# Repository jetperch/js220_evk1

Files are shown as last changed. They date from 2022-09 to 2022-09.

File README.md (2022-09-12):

# JS220 Evaluation Kit 1

Welcome to the Joulescope JS220 Evaluation Kit 1 (EVK) project.  This EVK
provides a quick and easy way to get started measuring real waveforms with
your Joulescope.  The goal of the EVK is to toggle signals to vary the load.  
Your JS220 will measure this change and display the current waveform in the 
Joulescope UI. 

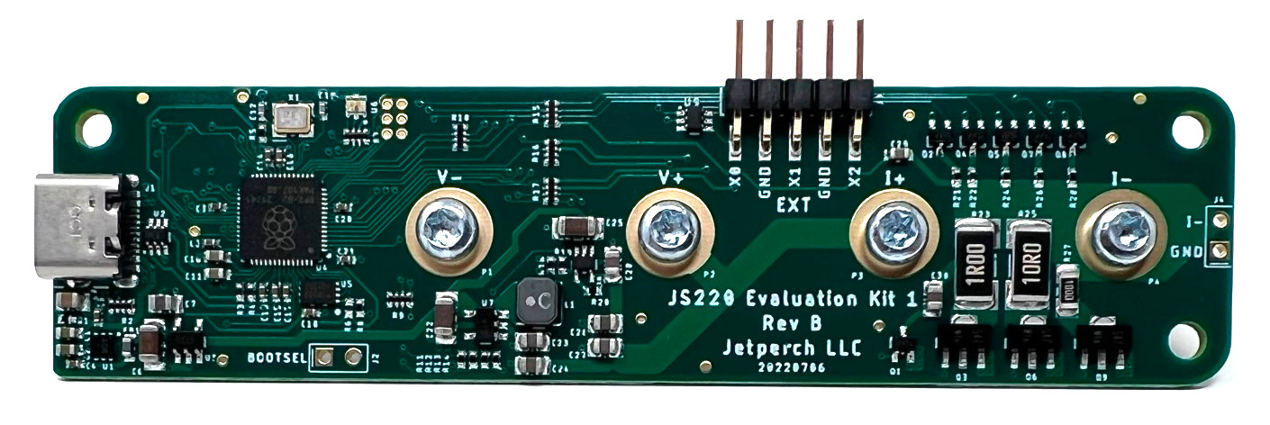
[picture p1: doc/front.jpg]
EVK1 board


To get started, connect your JS220 to your host computer.  Install and
start the Joulescope UI.  Select View → Oscilloscope.  

Now plug the EVK into your JS220, like this:

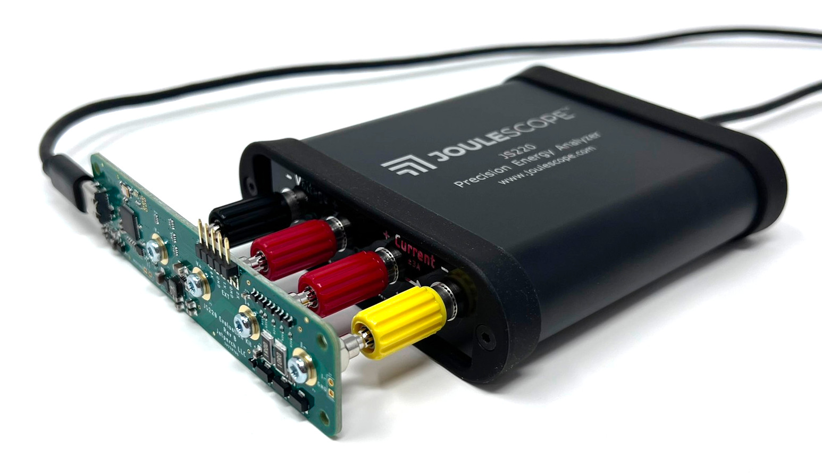
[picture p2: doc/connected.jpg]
EVK1 config


Use the provided USB-C to USB-A cable to connect the EVK to your
host computer.  The Joulescope UI should display an interesting waveform,
like this:

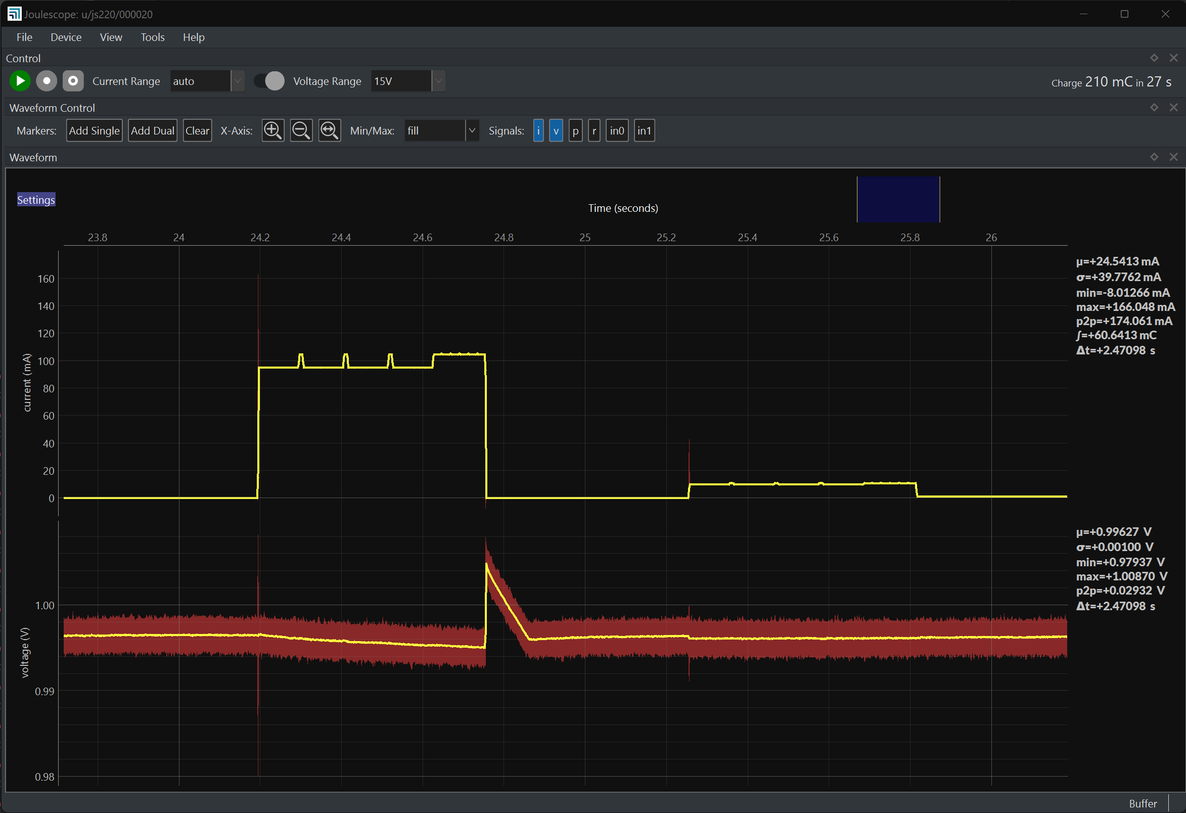
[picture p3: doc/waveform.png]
EVK1 waveform


The EVK hardware and firmware are open source and available on 
[GitHub](https://github.com/jetperch/js220_evk1).  View the 
[schematic](https://github.com/jetperch/js220_evk1/blob/main/hardware/js220_evk1.pdf).

The EVK produces this waveform by default.  The EVK is also very flexible.
The EVK runs MicroPython for easy configuration and programming over a
USB-CDC serial port interface.

To get started with MicroPython on your EVK:

1. Connect the EVK to your host computer using the provided USB cable.
2. Install [Thonny](https://thonny.org/)
3. Launch Thonny
4. Select Run → Select interpretter...
   a. Select MicroPython (Raspberry Pi Pico)
   b. Leave port set to <Try to detect port automatically>
   c. OK
5. The "Shell" area at the bottom should display the MicroPython banner ">>>"

You can then run some other tests or create your own.

To stop any load sequence and return to a high impedance load:

    evk.stop()

To power off the supply:

    evk.power_off()

To disable both power and load:

    evk.off()

To run the demo again:

    evk.demo()

To run a simple descending pattern with the buck converter:

    evk.current_range_tester(use_buck=True)

To run a more complicated descending patterh with the buck converter:

    evk.off()
    evk.power_buck(0.6)
    evk.pio_start_sequence(frequency=10_000, sequence='descend')

To provide 1 V from the LDO into a 1 kΩ load:

    evk.off()
    evk.power_ldo(1.0)
    evk.resistance = 1000

To provide 3.3V from the buck converter into a load 1 kΩ || 10 µF:

    evk.off()
    evk.power_ldo(1.0)
    evk.resistance = 1000
    evk.c_10U.on()

To enable both the 1 kΩ and 100 Ω resistors with the 10 µF capacitor:

    evk.stop()
    evk.resistance_on(1000)
    evk.resistance_on(100)
    evk.c_10U.on()

Alternatively:

    evk.stop()
    evk.resistance_mask_on(0x0C)
    evk.c_10U.on()

To disconnect the 10 µF capacitor:
    
    evk.c_10U.off()

To use the PWM capacitor to drive a bipolar current:

    evk.off()
    evk.power_ldo(3.3)
    evk.c_pwm_start(10_000, 0x8000)

To change the LED color to blue:
    
    led.u8(red=0, green=0, blue=255)

You can also animate the LED:

    led.animate_fade([0x00ff00, 0, 0])
    led.animate_rainbow()
    led.stop()

## References:

* [MicroPython](https://micropython.org/)
  * [GitHub](https://github.com/micropython/micropython)
* [Thonny](https://thonny.org/)
* [MicroPython on Raspberry Pi](https://www.raspberrypi.com/documentation/microcontrollers/micropython.html)
  * [Raspberry Pi Pico Python SDK](https://datasheets.raspberrypi.com/pico/raspberry-pi-pico-python-sdk.pdf)
  * [API documentation](https://docs.micropython.org/en/latest/library/rp2.html)
  * [Pico Micropython Examples](https://github.com/raspberrypi/pico-micropython-examples/)
* [Raspberry Pi RP2040 Documentation](https://www.raspberrypi.com/documentation/microcontrollers/rp2040.html)
  * [Pico PIO Examples](https://github.com/raspberrypi/pico-examples/tree/master/pio)
  * [Pico Examples](https://github.com/raspberrypi/pico-examples) for C SDK
    * [Logic Analyzer](https://github.com/raspberrypi/pico-examples/blob/master/pio/logic_analyser/logic_analyser.c) PIO + DMA
    * [PIO](https://github.com/raspberrypi/pico-examples/tree/master/pio)
    * [DMA](https://github.com/raspberrypi/pico-examples/tree/master/dma)
* Controlling the EVK from your host computer
  * [pyboard.py](https://github.com/micropython/micropython/blob/master/tools/pyboard.py)
  * [rshell](https://github.com/dhylands/rshell)
  * [ampy](https://github.com/scientifichackers/ampy)

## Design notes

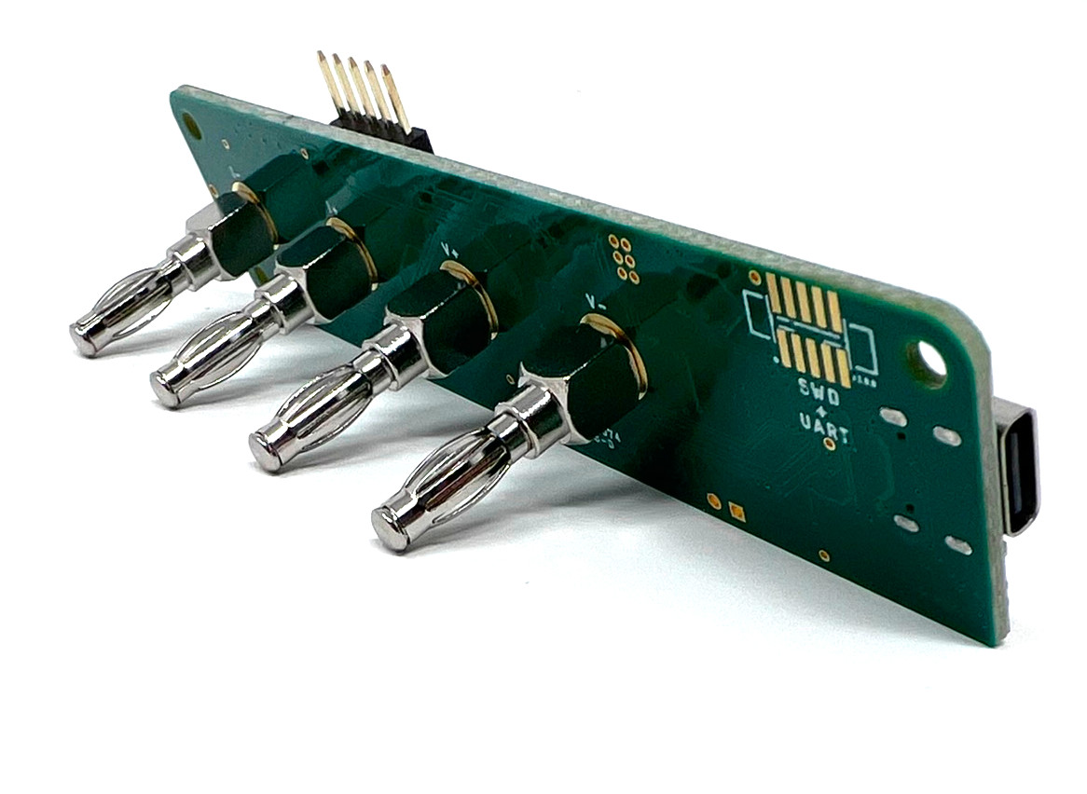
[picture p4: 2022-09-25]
doc/back.jpg

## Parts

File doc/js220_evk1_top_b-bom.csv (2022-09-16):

BOM Qty | Part/BOM Name | Description | Designators | Comments
1 | 6 x 5 x 2" White Box | 6 x 5 x 2" White Indestructo Mailers 100/bundle
1 | Anti-Static Self-Seal Bubble Bags 6 x 8 1/2" | Anti-Static Bubble Bags - Self-Seal, 6 x 8 1/2" 250/carton
1 | ESD warning label 2x2" | Static Warning Labels - "Attention…Electrostatic Sensitive Devices", 2 x 2" 500/roll
1 | USB_AM_CM_150_A | USB 2.0 high-speed 1.5 meter, black color, A male to C male, rev A
1 | js220_evk1_label | JS220 EVK1 UPC barcode label
1 | js220_evk1_pcba_b | JS220 Evaluation Kit 1, Printed Circuit Board Assembly, rev B
1 | js220_evk1_qs_a | JS220 Evaluation Kit 1 quick start guide, rev A

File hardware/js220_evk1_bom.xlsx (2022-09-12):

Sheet: All
BOM - All
2022 July 06
# | Qty | Ref Des | Name
1 | 2 | R3, R4 | R0402-27-1%
2 | 3 | R5, R8, R28 | R0402-1k-0.1%
3 | 1 | R13 | R0402-2.21k-0.1%
4 | 1 | R12 | R0402-2.8k-0.1%
5 | 1 | R19 | R0402-4.32k-1%
6 | 1 | R18 | R0402-8.45k-1%
7 | 4 | R11, R14, R20, R26 | R0402-10k-0.1%
8 | 1 | R24 | R0402-100k-0.1%
9 | 1 | R1 | R0402-267k-1%
10 | 1 | R22 | R0402-1M-1%
11 | 1 | R21 | R0402-10M-1%
12 | 1 | R27 | R1206-100-1%
13 | 1 | R23 | R2512-1-1%
14 | 1 | R25 | R2512-10-1%
15 | 3 | R7, R10, R16 | R4_0804-270-5%
16 | 2 | R15, R17 | R4_0804-1k-5%
17 | 2 | R2, R9 | R4_0804-4.7k-5%
18 | 2 | C12, C19 | C0402-30p-C0G-50V-5%
19 | 2 | C4, C5 | C0402-10n-X7R-50V-10%
20 | 10 | C8, C9, C13, C14, C15, C16, C17, C18, C20, C21 | C0402-100n-X7R-50V-10%
21 | 5 | C1, C2, C10, C11, C29 | C0603-1u-X5R-50V-20%
22 | 1 | C3 | C0805-1n-X5R-1000V-20%
23 | 7 | C7, C23, C24, C26, C27, C28, C30 | C0805-10u-X5R-6.3V-20%
24 | 3 | C6, C22, C25 | C1206-10u-X5R-10V-20%
25 | 1 | FB1 | FB0603_470
26 | 1 | L1 | NRS4018T2R2MDGJ
27 | 1 | X1 | ABM8-12.000MHZ-20-B1U-T
28 | 5 | Q2, Q4, Q5, Q7, Q8 | BC848W
29 | 1 | Q1 | BSS214NWH6327XTSA1
30 | 3 | Q3, Q6, Q9 | PBSS4240X
31 | 1 | U6 | 19-337C/RSBHGHC-A88/4T
32 | 1 | U3 | MIC5225-3.3YM5-TR
33 | 1 | U8 | MIC5377YC5-TR
34 | 1 | U1 | NCP361MUTBG
35 | 1 | U4 | RP2040
36 | 1 | U7 | TLV62565DBV
37 | 2 | U2, U9 | TPD4E1U06DCK
38 | 1 | U5 | W25Q16JVUXIQ TR
39 | 1 | J3 | M20-8890545R
40 | 1 | J1 | USB4105-GF-A
41 | 4 | P1, P2, P3, P4 | P55-271F40N
42 | 1 | PCB1 | JS220_evk1_pcb_revB
43 | 4 | U$1, U$2, U$3, U$4 | screw_0002
 | 89

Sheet: Top
BOM - Top
2022 July 06
# | Qty | Ref Des | Name
1 | 2 | R3, R4 | R0402-27-1%
2 | 3 | R5, R8, R28 | R0402-1k-0.1%
3 | 1 | R13 | R0402-2.21k-0.1%
4 | 1 | R12 | R0402-2.8k-0.1%
5 | 1 | R19 | R0402-4.32k-1%
6 | 1 | R18 | R0402-8.45k-1%
7 | 4 | R11, R14, R20, R26 | R0402-10k-0.1%
8 | 1 | R24 | R0402-100k-0.1%
9 | 1 | R1 | R0402-267k-1%
10 | 1 | R22 | R0402-1M-1%
11 | 1 | R21 | R0402-10M-1%
12 | 1 | R27 | R1206-100-1%
13 | 1 | R23 | R2512-1-1%
14 | 1 | R25 | R2512-10-1%
15 | 3 | R7, R10, R16 | R4_0804-270-5%
16 | 2 | R15, R17 | R4_0804-1k-5%
17 | 2 | R2, R9 | R4_0804-4.7k-5%
18 | 2 | C12, C19 | C0402-30p-C0G-50V-5%
19 | 2 | C4, C5 | C0402-10n-X7R-50V-10%
20 | 10 | C8, C9, C13, C14, C15, C16, C17, C18, C20, C21 | C0402-100n-X7R-50V-10%
21 | 5 | C1, C2, C10, C11, C29 | C0603-1u-X5R-50V-20%
22 | 1 | C3 | C0805-1n-X5R-1000V-20%
23 | 7 | C7, C23, C24, C26, C27, C28, C30 | C0805-10u-X5R-6.3V-20%
24 | 3 | C6, C22, C25 | C1206-10u-X5R-10V-20%
25 | 1 | FB1 | FB0603_470
26 | 1 | L1 | NRS4018T2R2MDGJ
27 | 1 | X1 | ABM8-12.000MHZ-20-B1U-T
28 | 5 | Q2, Q4, Q5, Q7, Q8 | BC848W
29 | 1 | Q1 | BSS214NWH6327XTSA1
30 | 3 | Q3, Q6, Q9 | PBSS4240X
31 | 1 | U6 | 19-337C/RSBHGHC-A88/4T
32 | 1 | U3 | MIC5225-3.3YM5-TR
33 | 1 | U8 | MIC5377YC5-TR
34 | 1 | U1 | NCP361MUTBG
35 | 1 | U4 | RP2040
36 | 1 | U7 | TLV62565DBV
37 | 2 | U2, U9 | TPD4E1U06DCK
38 | 1 | U5 | W25Q16JVUXIQ TR
39 | 1 | J3 | M20-8890545R
40 | 1 | J1 | USB4105-GF-A
41 | 4 | P1, P2, P3, P4 | P55-271F40N
42 | 1 | PCB1 | JS220_evk1_pcb_revB
43 | 4 | U$1, U$2, U$3, U$4 | screw_0002
 | 89

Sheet: Bottom
BOM - Bottom
2022 July 06
# | Qty | Ref Des | Name
 | 0

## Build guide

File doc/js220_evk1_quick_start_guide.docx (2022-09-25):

Joulescope JS220 Evaluation Kit 1

Quick Start Guide

This Joulescope™ JS220 Evaluation Kit 1 (EVK) provides a quick and easy way to measure real waveforms with a Joulescope JS220. Power the EVK with the provided USB C to A cable. The EVK plugs directly into the sensor-side of the JS220, and it generates high-dynamic current waveforms for analysis by the JS220.

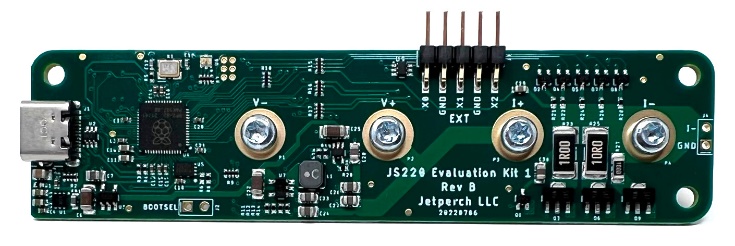
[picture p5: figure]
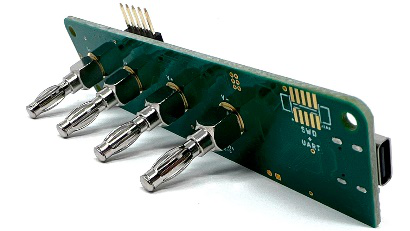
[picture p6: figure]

Kit Contents:

- JS220 EVK1 board
- USB A to C cable
- Joulescope sticker

You will need to provide a Joulescope JS220 and a host computer. The host computer must have two available USB A ports, one for the JS220 and one for the EVK.

1. Connect the EVK to the JS220 sensor-side binding posts. Use both hands and avoid the protruding expansion connector header.
2. Use the provided USB cable to connect the EVK to the host computer.
3. Use the JS220’s USB cable to connect the JS220 to the host computer.
4. Launch the Joulescope software to capture and explore!

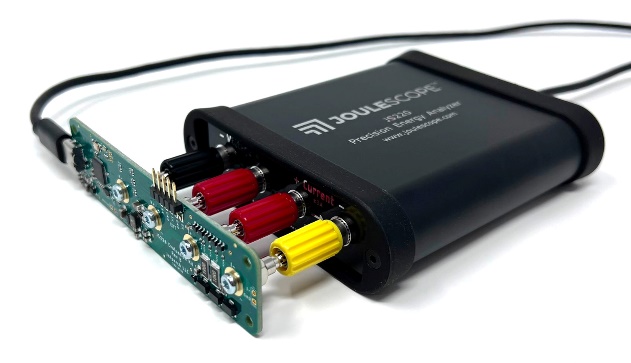
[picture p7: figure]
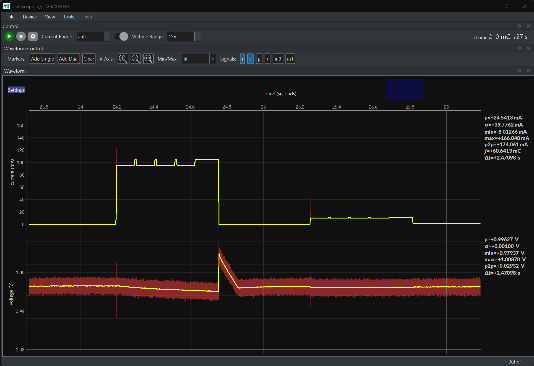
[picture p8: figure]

You can easily control the EVK to generate other waveforms and interact with GPIO. The entire hardware and software design is open source using Micropython. For more detailed instructions and information, visit joulescope.com/js220_evk1

⚠️ | The EVK is provided for evaluation only and does not have FCC, CE, or USB certifications. You are responsible for operating the EVK in compliance with any local regulations.

If you have any questions, please contact support@joulescope.com!

© 2022 Jetperch LLC Rev 2

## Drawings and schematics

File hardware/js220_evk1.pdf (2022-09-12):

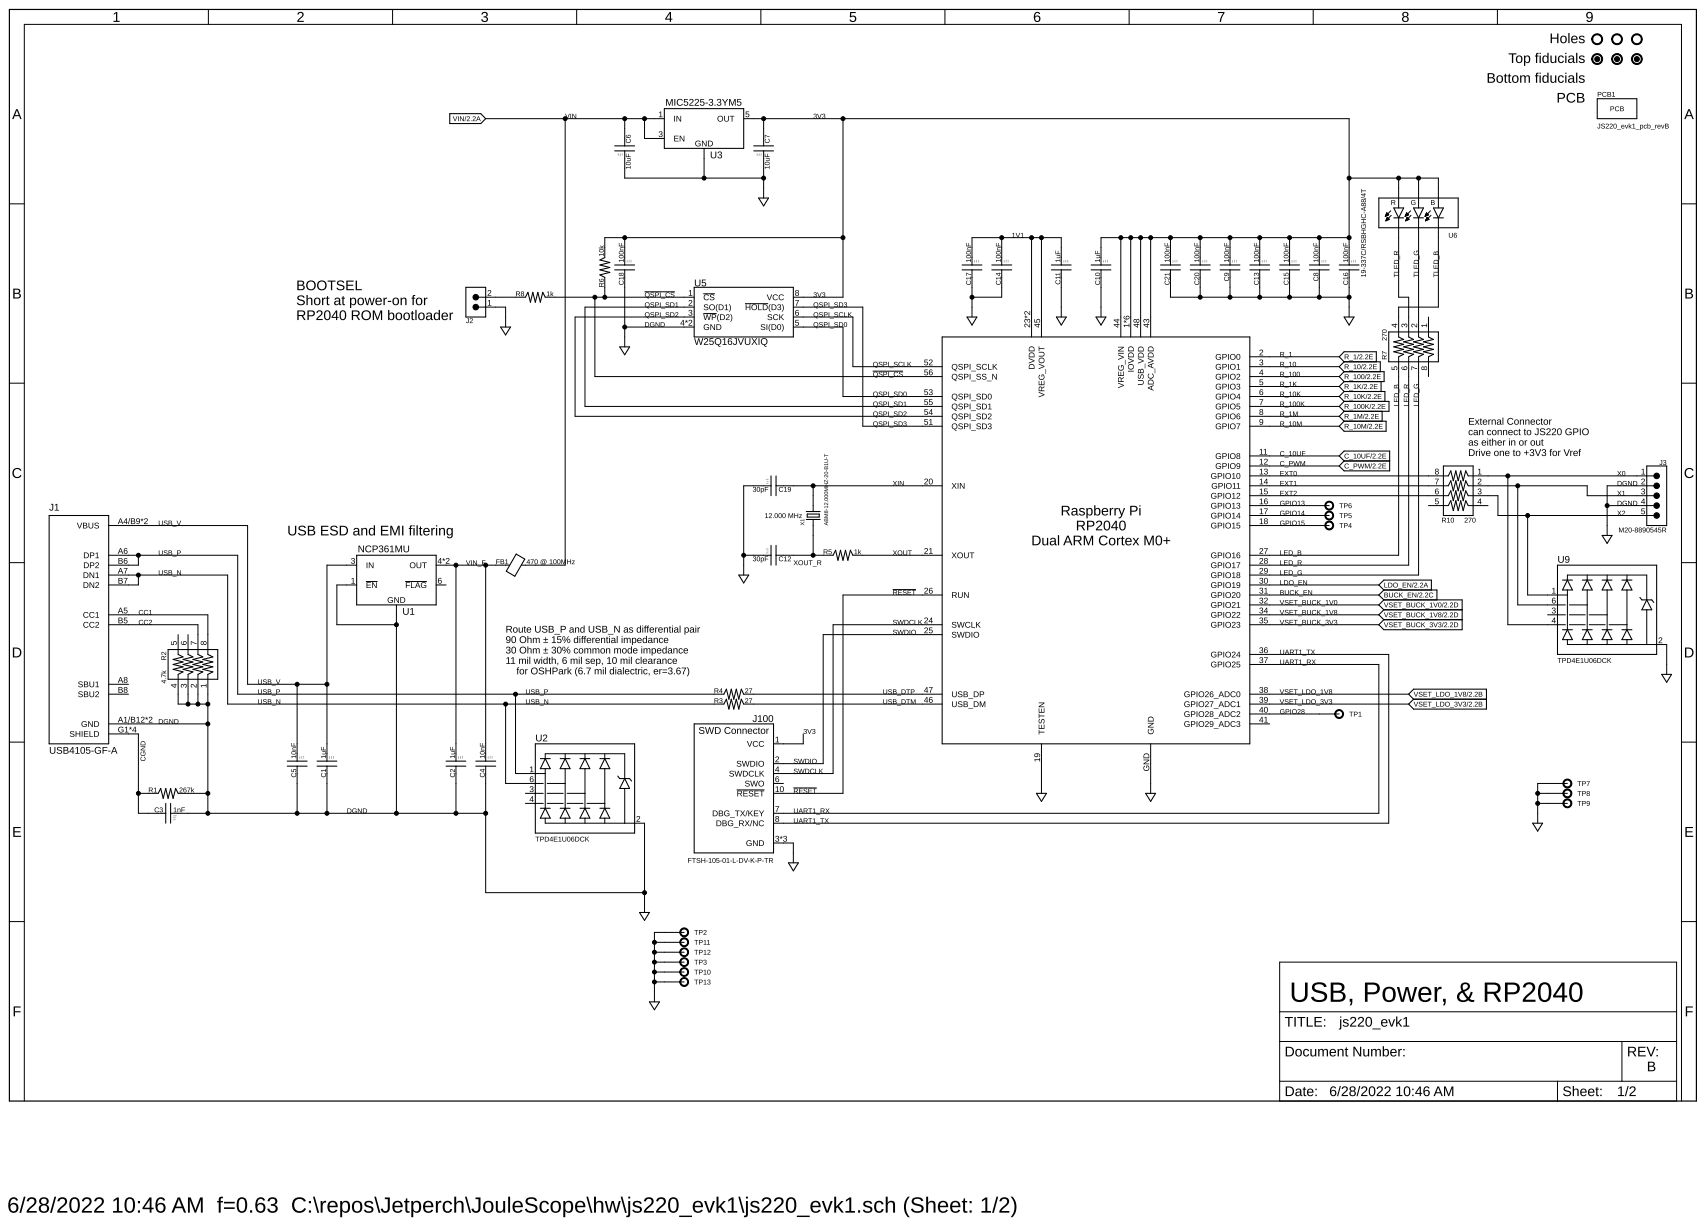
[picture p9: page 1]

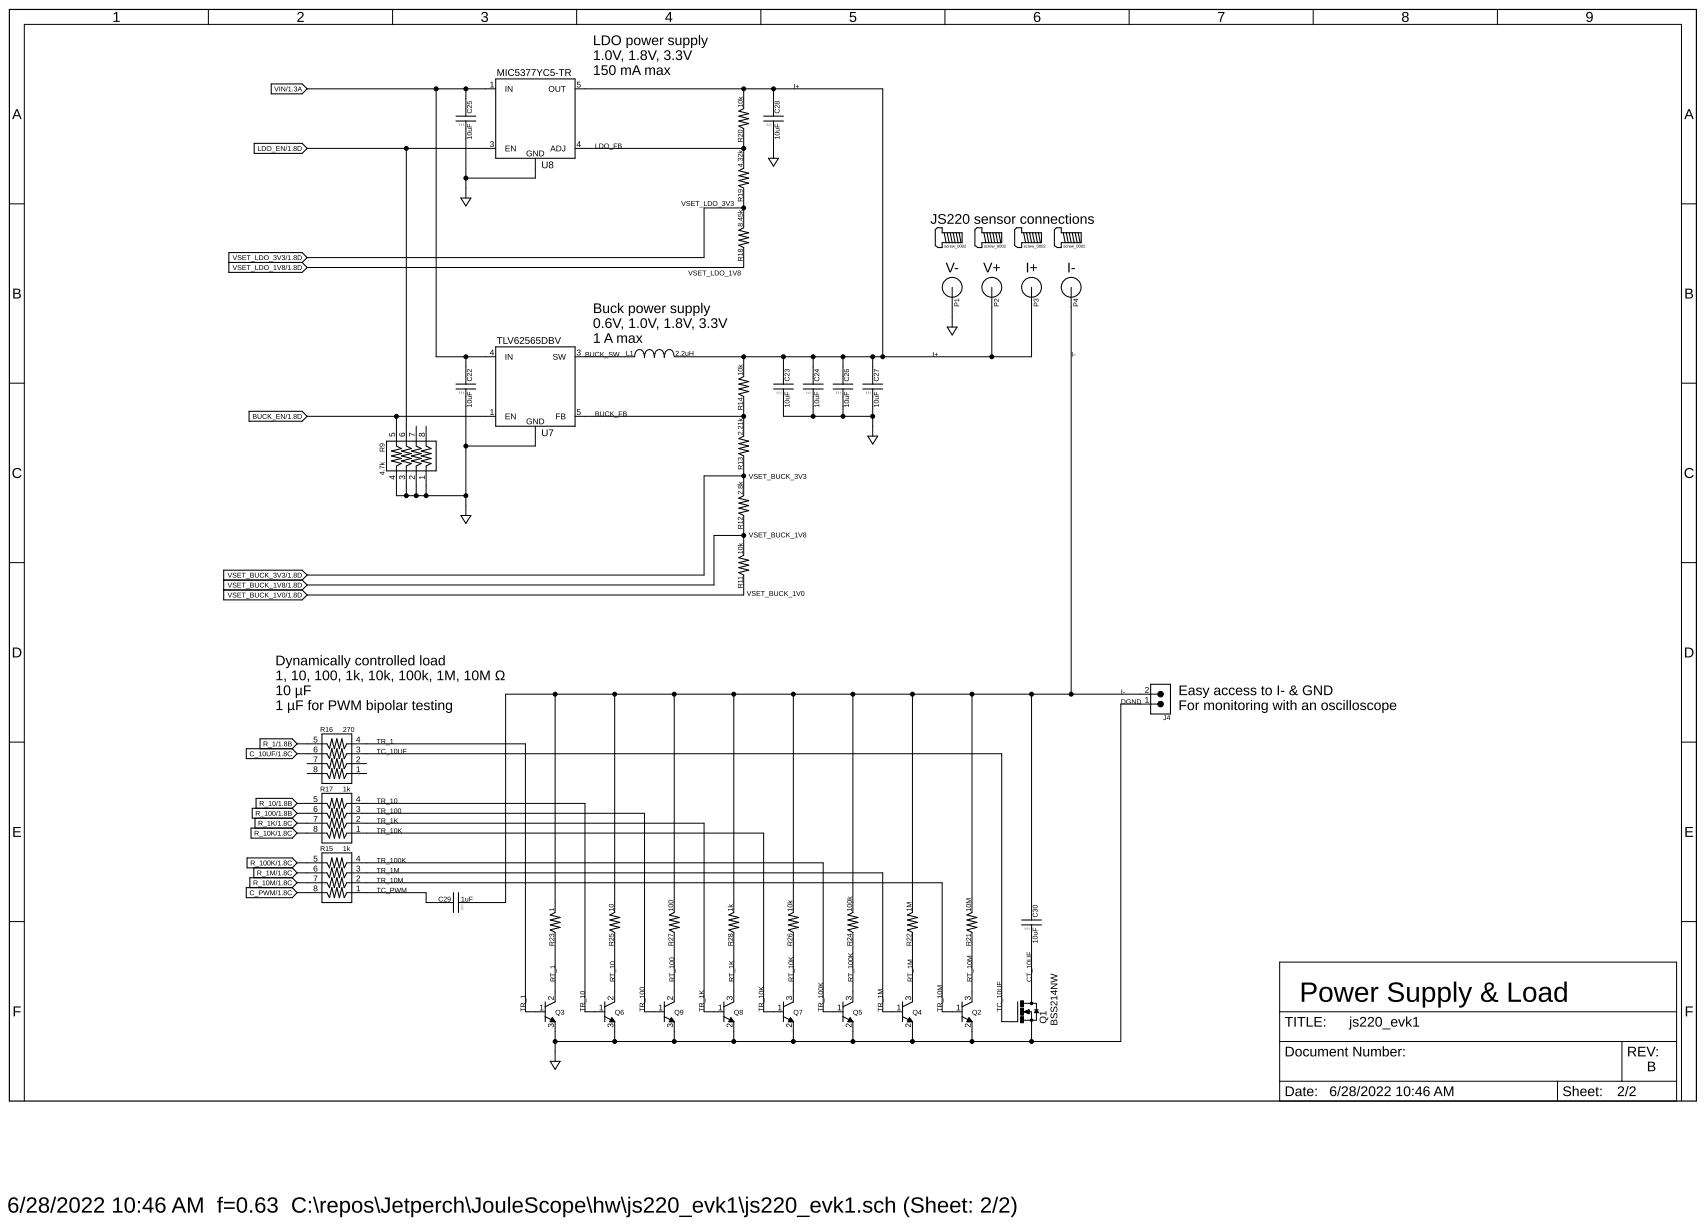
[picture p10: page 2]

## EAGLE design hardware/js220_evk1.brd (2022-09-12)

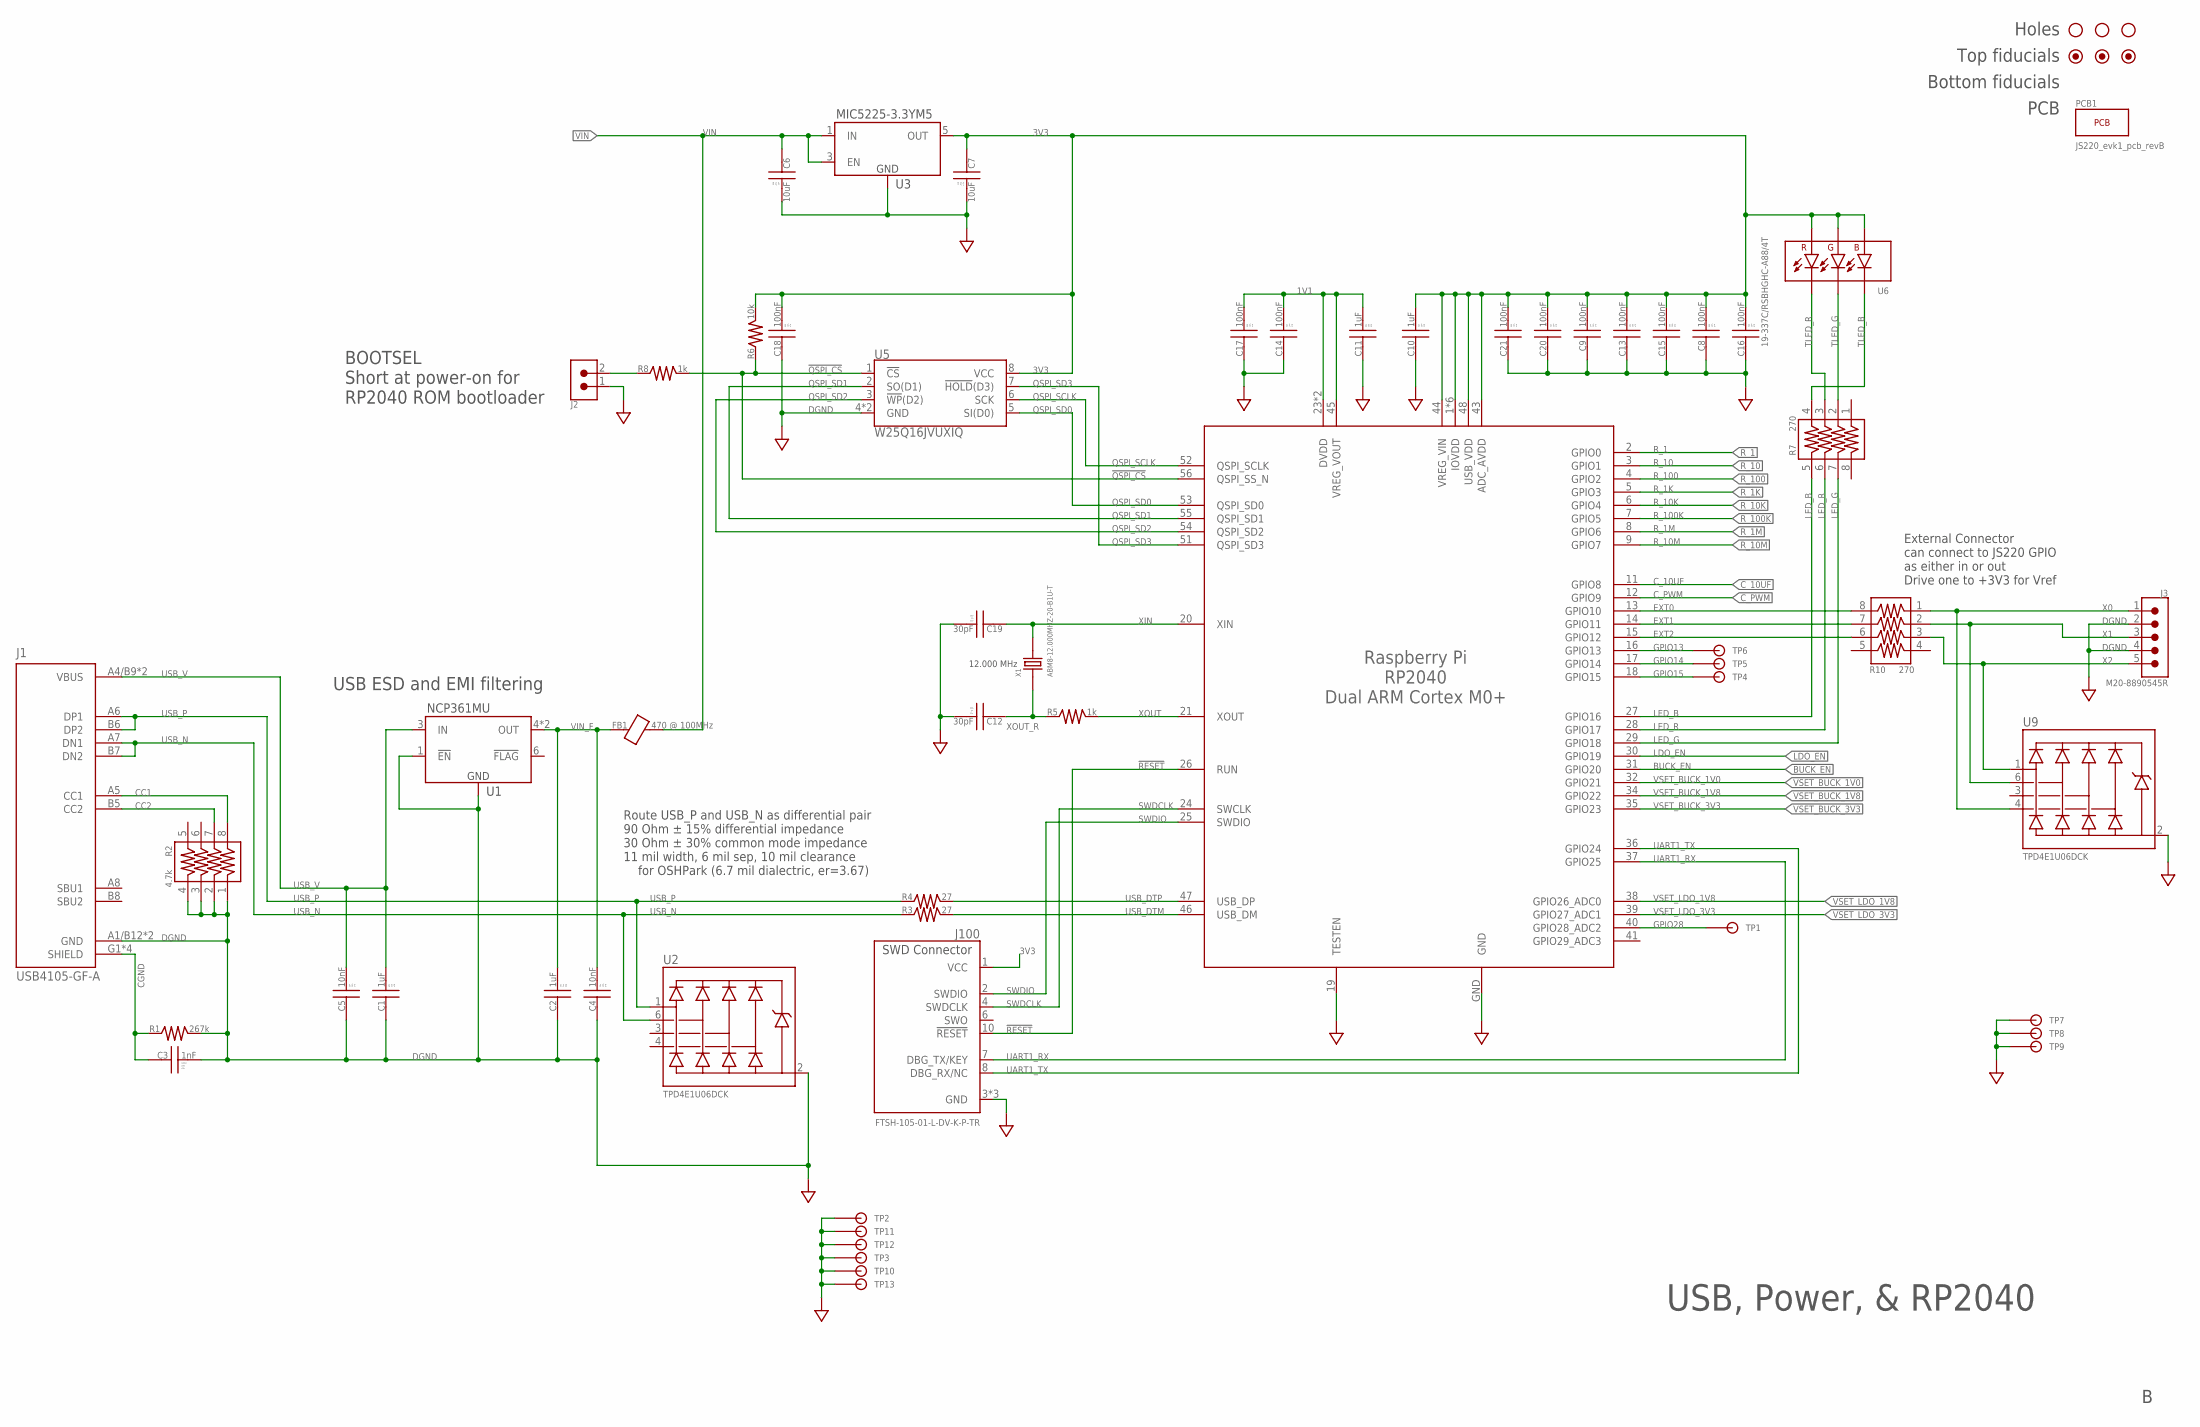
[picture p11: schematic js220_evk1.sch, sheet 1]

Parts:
C1, C2, C10, C11: 1uF; 0603; TOLERANCE 20%; VOLTAGE 50V
C3: 1nF; 0805; TOLERANCE 20%; VOLTAGE 1000V
C4, C5: 10nF; 0402; TOLERANCE 10%; VOLTAGE 50V
C6: 10uF; 1206; TOLERANCE 20%; VOLTAGE 10V
C7: 10uF; 0805; TOLERANCE 20%; VOLTAGE 6.3V
C8, C9, C13, C14, C15, C16, C17, C18, C20, C21: 100nF; 0402; TOLERANCE 10%; VOLTAGE 50V
C12, C19: 30pF; 0402; TOLERANCE 5%; VOLTAGE 50V
FB1: 470 @ 100MHz; 0603
FD1, FD2, FD3: DNI; FIDUCIAL_1MM_2MM
H1, H2, H3: STAND-OFFTIGHT; STAND-OFF-TIGHT
J1: USB4105-GF-A; GCT_USB4105_REVA; MPN USB4105-GF-A
J2: CONN_0.1_2X1; CONN_0.1_2X1_M
J3: M20-8890545R; CONN_0.1_5X1_MSR; MPN M20-8890545R
J100: FTSH-105-01-L-DV-K-P-TR; CONN_0.050_5X2_M_SM; MPN FTSH-105-01-L-DV-K-P-TR
R1: 267k; 0402; TOLERANCE 1%
R2: 4.7k; 0402X4; TOLERANCE 5%
R3, R4: 27; 0402; TOLERANCE 1%
R5, R8: 1k; 0402; TOLERANCE 0.1%
R6: 10k; 0402; TOLERANCE 0.1%
R7, R10: 270; 0402X4; TOLERANCE 5%
TP1, TP2, TP3, TP4, TP5, TP6, TP7, TP8, TP9, TP10, TP11, TP12, TP13: TPTP-PTH0.02; TP-PTH0.02
U1: NCP361MU; UDFN-6; MPN NCP361MUTBG
U2, U9: TPD4E1U06DCK; SC-70-6
U3: MIC5225-3.3YM5; SOT23-5; MPN MIC5225-3.3YM5-TR
U4: RP2040; QFN-56G; MPN RP2040
U5: W25Q16JVUXIQ; USON-8_2X3; MPN W25Q16JVUXIQ TR
U6: 19-337C/RSBHGHC-A88/4T; LED_RGB6_1.6X1.6; MPN 19-337C/RSBHGHC-A88/4T
X1: ABM8-12.000MHZ-20-B1U-T; XTAL4_3.2X2.5; MPN ABM8-12.000MHZ-20-B1U-T

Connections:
1V1: C11.2, C14.2, C17.2, U4.23 (DVDD), U4.45 (VREG_VOUT), U4.50 (DVDD)
3V3: C7.1, C8.2, C9.2, C10.2, C13.2, C15.2, C16.2, C18.2, C20.2, C21.2, J100.1 (VCC), R6.2, U3.5 (OUT), U4.1 (IOVDD), U4.10 (IOVDD), U4.22 (IOVDD), U4.33 (IOVDD), U4.42 (IOVDD), U4.43 (ADC_AVDD), U4.44 (VREG_VIN), U4.48 (USB_VDD), U4.49 (IOVDD), U5.8 (VCC), U6.2 (GREEN_ANODE+), U6.4 (RED_ANODE+), U6.6 (BLUE_ANODE+)
!QSPI_CS: R6.1, R8.2, U4.56 (QSPI_SS_N), U5.1 (!CS!)
!RESET: J100.10 (!RESET), U4.26 (RUN)
BUCK_EN: U4.31 (GPIO20); also elsewhere on the board
CC1: J1.A5 (CC1), R2.8 (1B)
CC2: J1.B5 (CC2), R2.7 (2B)
CGND: C3.1, J1.G1 (SHIELD), J1.G2 (SHIELD), J1.G3 (SHIELD), J1.G4 (SHIELD), R1.1
C_10UF: U4.11 (GPIO8); also elsewhere on the board
C_PWM: U4.12 (GPIO9); also elsewhere on the board
DGND: C1.1, C2.1, C3.2, C4.1, C5.1, C6.2, C7.2, C8.1, C9.1, C10.1, C11.1, C12.2, C13.1, C14.1, C15.1, C16.1, C17.1, C18.1, C19.2, C20.1, C21.1, J1.A1/B12 (GND), J1.B1/A12 (GND), J2.1, J3.2, J3.4, J100.3 (GND), J100.5 (GND), J100.9 (GND), R1.2, R2.1 (1A), R2.2 (2A), R2.3 (3A), R2.4 (4A), TP2.1, TP3.1, TP7.1, TP8.1, TP9.1, TP10.1, TP11.1, TP12.1, TP13.1, U1.1 (!EN), U1.2 (GND), U1.GND@PAD (GND), U2.2 (GND), U3.2 (GND), U4.19 (TESTEN), U4.GND, U5.4 (GND), U5.9 (GND), U9.2 (GND); also elsewhere on the board
EXT0: R10.8 (1B), U4.13 (GPIO10)
EXT1: R10.7 (2B), U4.14 (GPIO11)
EXT2: R10.6 (3B), U4.15 (GPIO12)
GPIO13: TP6.1, U4.16 (GPIO13)
GPIO14: TP5.1, U4.17 (GPIO14)
GPIO15: TP4.1, U4.18 (GPIO15)
GPIO28: TP1.1, U4.40 (GPIO28_ADC2)
LDO_EN: U4.30 (GPIO19); also elsewhere on the board
LED_B: R7.5 (4B), U4.27 (GPIO16)
LED_G: R7.7 (2B), U4.29 (GPIO18)
LED_R: R7.6 (3B), U4.28 (GPIO17)
unnamed: J2.2, R8.1
QSPI_SCLK: U4.52 (QSPI_SCLK), U5.6 (SCK)
QSPI_SD0: U4.53 (QSPI_SD0), U5.5 (SI(D0))
QSPI_SD1: U4.55 (QSPI_SD1), U5.2 (SO(D1))
QSPI_SD2: U4.54 (QSPI_SD2), U5.3 (!WP!(D2))
QSPI_SD3: U4.51 (QSPI_SD3), U5.7 (!HOLD!(D3))
R_1: U4.2 (GPIO0); also elsewhere on the board
R_1K: U4.5 (GPIO3); also elsewhere on the board
R_1M: U4.8 (GPIO6); also elsewhere on the board
R_10: U4.3 (GPIO1); also elsewhere on the board
R_10K: U4.6 (GPIO4); also elsewhere on the board
R_10M: U4.9 (GPIO7); also elsewhere on the board
R_100: U4.4 (GPIO2); also elsewhere on the board
R_100K: U4.7 (GPIO5); also elsewhere on the board
SWDCLK: J100.4 (SWDCLK), U4.24 (SWCLK)
SWDIO: J100.2 (SWDIO), U4.25 (SWDIO)
TLED_B: R7.4 (4A), U6.5 (BLUE_CATHODE-)
TLED_G: R7.2 (2A), U6.1 (GREEN_CATHODE-)
TLED_R: R7.3 (3A), U6.3 (RED_CATHODE-)
UART1_RX: J100.7 (DBG_TX/KEY), U4.37 (GPIO25)
UART1_TX: J100.8 (DBG_RX/NC), U4.36 (GPIO24)
USB_DTM: R3.2, U4.46 (USB_DM)
USB_DTP: R4.2, U4.47 (USB_DP)
USB_N: J1.A7 (DN1), J1.B7 (DN2), R3.1, U2.6 (D1-)
USB_P: J1.A6 (DP1), J1.B6 (DP2), R4.1, U2.1 (D1+)
USB_V: C1.2, C5.2, J1.A4/B9 (VBUS), J1.B4/A9 (VBUS), U1.3 (IN)
VIN: C6.1, FB1.2, U3.1 (IN), U3.3 (EN); also elsewhere on the board
VIN_F: C2.2, C4.2, FB1.1, U1.4 (OUT), U1.5 (OUT)
VSET_BUCK_1V0: U4.32 (GPIO21); also elsewhere on the board
VSET_BUCK_1V8: U4.34 (GPIO22); also elsewhere on the board
VSET_BUCK_3V3: U4.35 (GPIO23); also elsewhere on the board
VSET_LDO_1V8: U4.38 (GPIO26_ADC0); also elsewhere on the board
VSET_LDO_3V3: U4.39 (GPIO27_ADC1); also elsewhere on the board
X0: J3.1, R10.1 (1A), U9.4 (D2-)
X1: J3.3, R10.2 (2A), U9.6 (D1-)
X2: J3.5, R10.3 (3A), U9.1 (D1+)
XIN: C19.1, U4.20 (XIN), X1.3 (2)
XOUT: R5.2, U4.21 (XOUT)
XOUT_R: C12.1, R5.1, X1.1

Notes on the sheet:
USB, Power, & RP2040
USB ESD and EMI filtering
Route USB_P and USB_N as differential pair 90 Ohm ± 15% differential impedance 30 Ohm ± 30% common mode impedance 11 mil width, 6 mil sep, 10 mil clearance for OSHPark (6.7 mil dialectric, er=3.67)
12.000 MHz
Holes Top fiducials Bottom fiducials PCB
External Connector can connect to JS220 GPIO as either in or out Drive one to +3V3 for Vref
BOOTSEL Short at power-on for RP2040 ROM bootloader

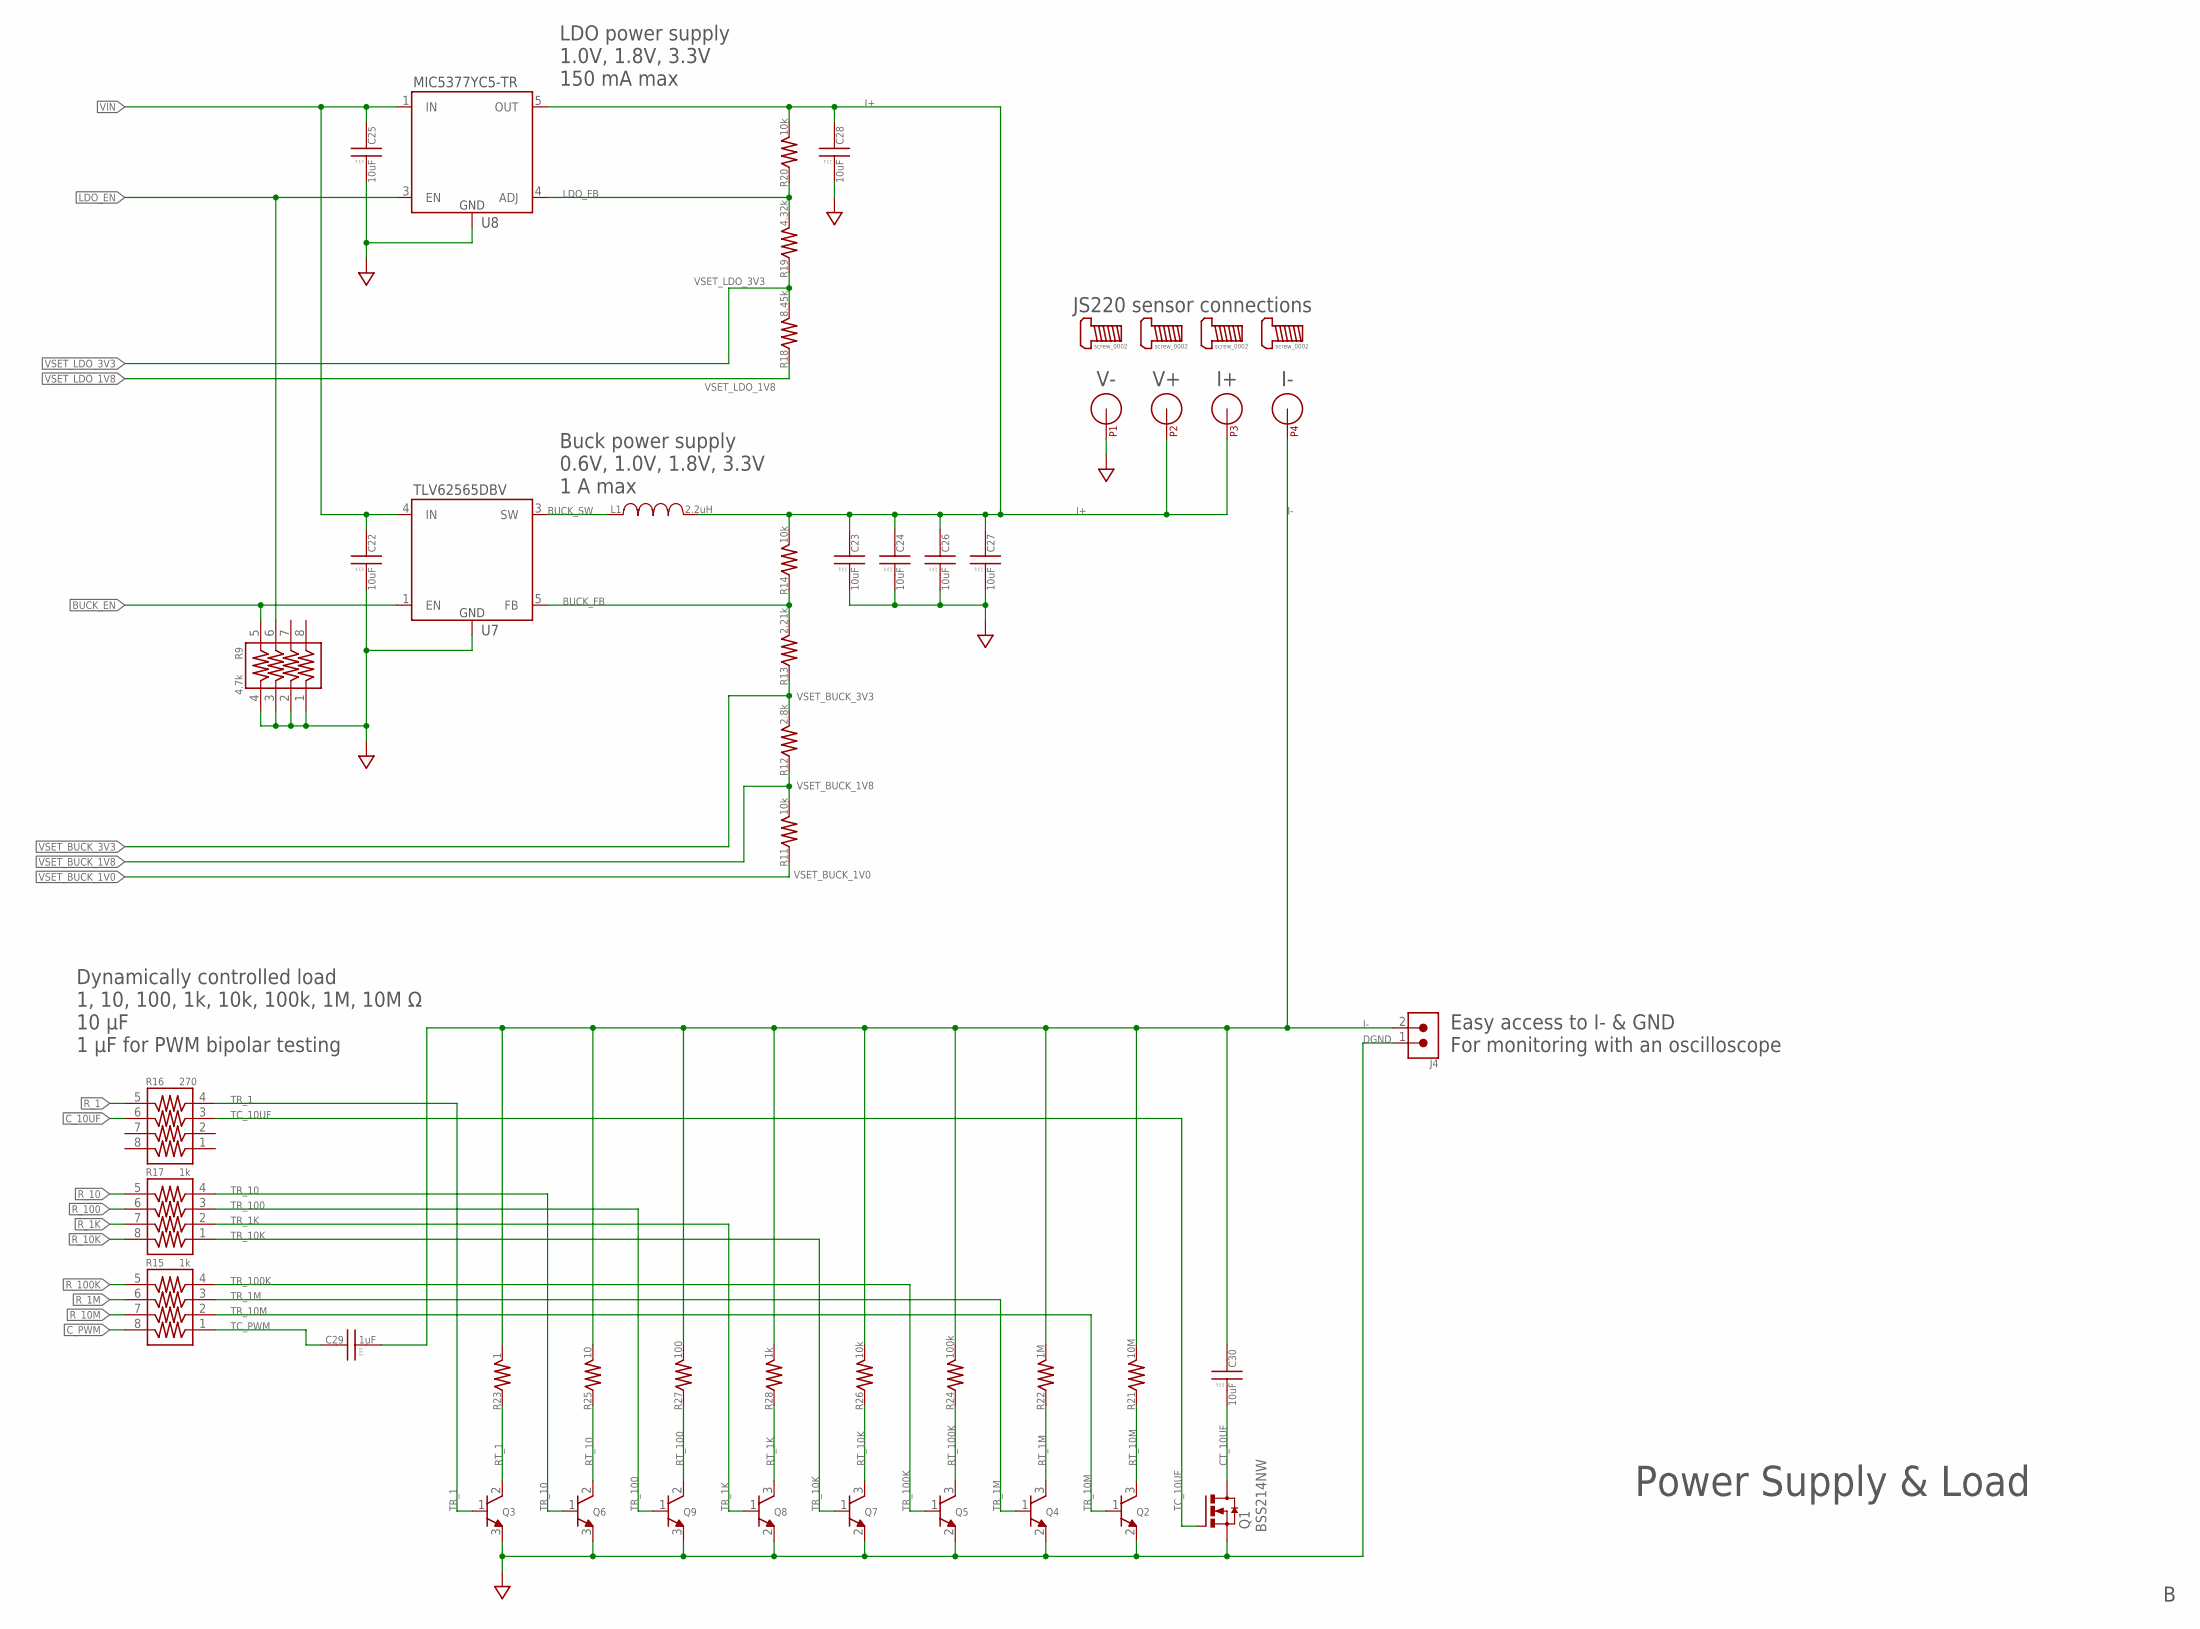
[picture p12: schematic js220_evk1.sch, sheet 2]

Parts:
C22, C25: 10uF; 1206; TOLERANCE 20%; VOLTAGE 10V
C23, C24, C26, C27, C28, C30: 10uF; 0805; TOLERANCE 20%; VOLTAGE 6.3V
C29: 1uF; 0603; TOLERANCE 20%; VOLTAGE 50V
J4: CONN_0.1_2X1; CONN_0.1_2X1_M
L1: 2.2uH; LPS4018; MPN NRS4018T2R2MDGJ
P1, P2, P3, P4: P55-271F40N; 72918
Q1: BSS214NW; SOT323-3; MPN BSS214NWH6327XTSA1
Q2, Q4, Q5, Q7, Q8: BC848W; SOT323-3
Q3, Q6, Q9: PBSS4240X; SOT-89; MPN PBSS4240X
R9: 4.7k; 0402X4; TOLERANCE 5%
R11, R14, R20, R26: 10k; 0402; TOLERANCE 0.1%
R12: 2.8k; 0402; TOLERANCE 0.1%
R13: 2.21k; 0402; TOLERANCE 0.1%
R15, R17: 1k; 0402X4; TOLERANCE 5%
R16: 270; 0402X4; TOLERANCE 5%
R18: 8.45k; 0402; TOLERANCE 1%
R19: 4.32k; 0402; TOLERANCE 1%
R21: 10M; 0402; TOLERANCE 1%
R22: 1M; 0402; TOLERANCE 1%
R23: 1; 2512; TOLERANCE 1%
R24: 100k; 0402; TOLERANCE 0.1%
R25: 10; 2512; TOLERANCE 1%
R27: 100; 1206; TOLERANCE 1%
R28: 1k; 0402; TOLERANCE 0.1%
U7: TLV62565DBV; SOT23-5; MPN TLV62565DBV
U8: MIC5377YC5-TR; SC-70-5; MPN MIC5377YC5-TR

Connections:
BUCK_EN: R9.5 (4B), U7.1 (EN); also elsewhere on the board
BUCK_FB: R13.2, R14.1, U7.5 (FB)
BUCK_SW: L1.1, U7.3 (SW)
CT_10UF: C30.2, Q1.3 (D)
C_10UF: R16.6 (3B); also elsewhere on the board
C_PWM: R15.8 (1B); also elsewhere on the board
DGND: C22.2, C23.2, C24.2, C25.2, C26.2, C27.2, C28.2, J4.1, P1.1, Q1.2 (S), Q2.2 (EMITTER), Q3.3 (EMITTER), Q4.2 (EMITTER), Q5.2 (EMITTER), Q6.3 (EMITTER), Q7.2 (EMITTER), Q8.2 (EMITTER), Q9.3 (EMITTER), R9.1 (1A), R9.2 (2A), R9.3 (3A), R9.4 (4A), U7.2 (GND), U8.2 (GND); also elsewhere on the board
I+: C23.1, C24.1, C26.1, C27.1, C28.1, L1.2, P2.1, P3.1, R14.2, R20.2, U8.5 (OUT)
I-: C29.2, C30.1, J4.2, P4.1, R21.2, R22.2, R23.2, R24.2, R25.2, R26.2, R27.2, R28.2
LDO_EN: R9.6 (3B), U8.3 (EN); also elsewhere on the board
LDO_FB: R19.2, R20.1, U8.4 (ADJ)
RT_1: Q3.2 (COLLECTOR), R23.1
RT_1K: Q8.3 (COLLECTOR), R28.1
RT_1M: Q4.3 (COLLECTOR), R22.1
RT_10: Q6.2 (COLLECTOR), R25.1
RT_10K: Q7.3 (COLLECTOR), R26.1
RT_10M: Q2.3 (COLLECTOR), R21.1
RT_100: Q9.2 (COLLECTOR), R27.1
RT_100K: Q5.3 (COLLECTOR), R24.1
R_1: R16.5 (4B); also elsewhere on the board
R_1K: R17.7 (2B); also elsewhere on the board
R_1M: R15.6 (3B); also elsewhere on the board
R_10: R17.5 (4B); also elsewhere on the board
R_10K: R17.8 (1B); also elsewhere on the board
R_10M: R15.7 (2B); also elsewhere on the board
R_100: R17.6 (3B); also elsewhere on the board
R_100K: R15.5 (4B); also elsewhere on the board
TC_10UF: Q1.1 (G), R16.3 (3A)
TC_PWM: C29.1, R15.1 (1A)
TR_1: Q3.1 (BASE), R16.4 (4A)
TR_1K: Q8.1 (BASE), R17.2 (2A)
TR_1M: Q4.1 (BASE), R15.3 (3A)
TR_10: Q6.1 (BASE), R17.4 (4A)
TR_10K: Q7.1 (BASE), R17.1 (1A)
TR_10M: Q2.1 (BASE), R15.2 (2A)
TR_100: Q9.1 (BASE), R17.3 (3A)
TR_100K: Q5.1 (BASE), R15.4 (4A)
VIN: C22.1, C25.1, U7.4 (IN), U8.1 (IN); also elsewhere on the board
VSET_BUCK_1V0: R11.1; also elsewhere on the board
VSET_BUCK_1V8: R11.2, R12.1; also elsewhere on the board
VSET_BUCK_3V3: R12.2, R13.1; also elsewhere on the board
VSET_LDO_1V8: R18.1; also elsewhere on the board
VSET_LDO_3V3: R18.2, R19.1; also elsewhere on the board

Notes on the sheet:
Power Supply & Load
Easy access to I- & GND For monitoring with an oscilloscope
JS220 sensor connections
LDO power supply 1.0V, 1.8V, 3.3V 150 mA max
Buck power supply 0.6V, 1.0V, 1.8V, 3.3V 1 A max
Dynamically controlled load 1, 10, 100, 1k, 10k, 100k, 1M, 10M Ω 10 µF 1 µF for PWM bipolar testing

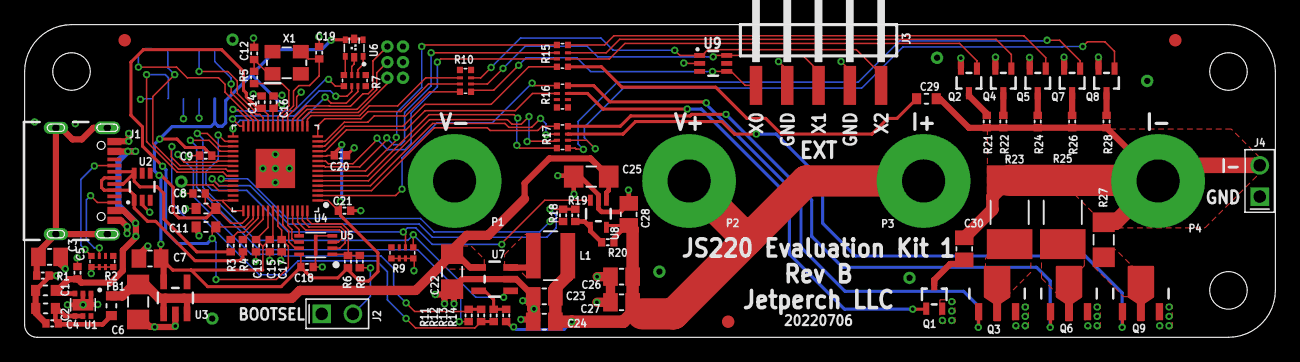
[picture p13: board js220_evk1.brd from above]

Board: 4 copper layers, 101.6 x 25.4 mm, 109 parts (1 on the bottom side), 85 nets.

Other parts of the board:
DOCFIELD_PCB: DOCFIELD
FRAME_PCB: FRAME_A_L

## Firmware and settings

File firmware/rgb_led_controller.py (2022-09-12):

# Copyright 2022 Jetperch LLC
#
# Licensed under the Apache License, Version 2.0 (the "License");
# you may not use this file except in compliance with the License.
# You may obtain a copy of the License at
#
#     http://www.apache.org/licenses/LICENSE-2.0
#
# Unless required by applicable law or agreed to in writing, software
# distributed under the License is distributed on an "AS IS" BASIS,
# WITHOUT WARRANTIES OR CONDITIONS OF ANY KIND, either express or implied.
# See the License for the specific language governing permissions and
# limitations under the License.

"""Control an RGB LED.

This library uses a 32-bit integer to represent colors with
4 8-bit (byte) channels: red, green, blue, alpha.
The channels are packed in little-endian format:
    31:24  alpha (ignored)
    23:16  blue
    15:8   green
    7:0    red
"""

import math
from machine import Timer


def _rgba_blend(v1, v2, f):
    c = 0
    for i in range(4):
        shift = 8 * i
        x1 = (v1 >> shift) & 0xff
        x2 = (v2 >> shift) & 0xff
        y = ((x1 * (0xffff - f)) + x2 * f) >> 16  # linear blend
        c |= (y & 0xff) << shift
    return c


_hsv_lookup = {
    0: (3, 2, 0),
    1: (1, 3, 0),
    2: (0, 3, 2),
    3: (0, 1, 3),
    4: (2, 0, 3),
    5: (3, 0, 1),
}


_trans_pride_white = 0x00f0_d0ff
_trans_pride_blue = 0x00f0_a055
_trans_pride_pink = 0x0098_70ff  # 0x009966ff
TRANS_PRIDE_COLORS = [_trans_pride_blue, _trans_pride_pink, _trans_pride_white,
                      _trans_pride_pink, _trans_pride_blue]


def _u8_saturate(v):
    return min(255, max(0, int(v)))


def hsv_u8_to_rgb_u32(h, s, v):
    """Convert HSV to RGB.

    :param h: The hue from 0 to 255.
    :param s: The saturation from 0 to 255.
    :param v: The value from 0 to 255.
    :return: The u32 RGB value.

    http://www.easyrgb.com/index.php?X=MATH&H=21#text21
    """
    h = (h & 0xff) / 256.0
    s = _u8_saturate(s) / 255.0
    v = _u8_saturate(v)
    if s == 0:
        return v | (v << 8) | (v << 16)
    h *= 6.0
    i = int(math.floor(h))
    f = h - i  # fractional part of h
    x = int(v * (1.0 - s))
    y = int(v * (1.0 - s * f))
    z = int(v * (1.0 - s * (1.0 - f)))
    w = v
    colors = [x, y, z, w, 0]
    k = _hsv_lookup.get(i, (4, 4, 4))
    r, g, b = colors[k[0]], colors[k[1]], colors[k[2]]
    return r | (g << 8) | (b << 16)


def color_sequence_extend(colors, n=None):
    """Extend the color sequence to stay at each color longer betweed fades.

    :param colors: The list of colors.
    :param n: The number of times to repeat each color.
        None (default) is 2.
    """
    if n is None:
        n = 2
    else:
        n = int(n)
    assert(n >= 1)

    result = []
    for c in colors:
        for _ in range(n):
            result.append(c)
    return result


class RgbLedController:
    """Control an RGB LED to produce lighting effects.

    :param cbk_rgb_u32: The callable(u32) to set the LED.  The u32
        value is 23:16 blue, 15:8 green, 7:0 red.

    The controller can set fixed LED values or produce animations
    that cycle through colors.

    To set colors directly:
        led.u32 = 0x0000FF  # red
        led.u32 = 0x00FF00  # green
        led.u32 = 0xFF0000  # blue
        led.u32 = 0xFF00FF  # magenta

    Or using u8:
        led.u8(0xff, 0x00, 0xff)  # magenta
        led.u8(red=0xff, green=0x00, blue=0xff)  # magenta

    To only change the green intensity:
        led.u8(green=128)

    To blink between red, white, and blue with the default period:
        led.animate_blink([0x0000_00FF, 0x00FF_FFFF, 0x00FF_0000])

    To blink between red, white, and blue with a 1 second period:
        led.animate_blink([0x0000_00FF, 0x00FF_FFFF, 0x00FF_0000], period_ms=1000)

    To fade between red, white, and blue:
        led.animate_fade([0x0000_00FF, 0x00FF_FFFF, 0x00FF_0000])

    To sequence with less fade duration and more pausing at each color:
        colors = color_sequence_extend([0x0000_00FF, 0x00FF_FFFF, 0x00FF_0000], n=3)
        led.animate_fade(colors, period_ms=3000)

    To display a rainbow with the default period:
        led.animate_rainbow()

    To display the trans pride flag colors:
        led.animate_trans_pride()

    To stop all animations and keep the current color:
        led.stop()

    To stop all animations and turn the LED off:
        led.off()
    """

    def __init__(self, cbk_rgb_u32):
        self._cbk_rgb_u32 = cbk_rgb_u32
        self._counter = 0
        self._velocity = 0
        self._saturation = 0
        self._value = 0
        self._colors = None
        self._color_now = 0
        self._timer = Timer()
        self._period_ms = 10  # 100 Hz

    @property
    def u32(self):
        """Get the present LED intensity."""
        return self._color_now

    @u32.setter
    def u32(self, value):
        """Directly set the LED intensity.

        If an animation is running, the sequence will
        quickly overwrite any manually set value.  You will need
        to :meth:`stop` first.
        """
        self._color_now = value
        self._cbk_rgb_u32(value)

    def u8(self, red=None, green=None, blue=None):
        """Set the LED color given independent u8 values.

        :param red: The red intensity from 0 to 255.
        :param green: The green intensity from 0 to 255.
        :param blue: The blue intensity from 0 to 255.

        A default None value keeps the existing intensity of that color.
        """
        u32 = self.u32
        if red is not None:
            r = _u8_saturate(red)
            u32 = (u32 & 0xffff_ff00) | r
        if green is not None:
            g = _u8_saturate(green)
            u32 = (u32 & 0xffff_00ff) | (g << 8)
        if blue is not None:
            b = _u8_saturate(blue)
            u32 = (u32 & 0xff00_ffff) | (b << 16)
        self.u32 = u32

    def animate_blink(self, colors, period_ms=None):
        """Start an animation for a exact color sequence.

        :param colors: The list of color values as u32.
        :param period_ms: The time to cycle through all colors in milliseconds.
        """
        if not len(colors):
            self.stop()
            return
        if period_ms is None:
            period_ms = 2000
        self._colors = colors
        self._value = 0
        period = period_ms // len(colors)
        self.u32 = colors[0]
        self._timer.init(period=period, callback=self._process_blink)

    def animate_fade(self, colors, period_ms=None):
        """Start an animation for an smoothly fading color sequence.
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

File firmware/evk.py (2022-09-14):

# Copyright 2022 Jetperch LLC
#
# Licensed under the Apache License, Version 2.0 (the "License");
# you may not use this file except in compliance with the License.
# You may obtain a copy of the License at
#
#     http://www.apache.org/licenses/LICENSE-2.0
#
# Unless required by applicable law or agreed to in writing, software
# distributed under the License is distributed on an "AS IS" BASIS,
# WITHOUT WARRANTIES OR CONDITIONS OF ANY KIND, either express or implied.
# See the License for the specific language governing permissions and
# limitations under the License.

"""
JS220 Evaluation Kit 1 (EVK) MicroPython code.

MicroPython with the Raspberry PI RP2040 microcontroller has five different
ways to toggle signals over time:
1. GPIO set from REPL
2. GPIO set from for/while loop with time.sleep()
3. GPIO set from machine.Timer ISR
4. PWM
5. PIO

The PIO approach is the best for fast, controlled waveforms.  The EVK
provides a simple way to generate patterns.
"""

import micropython
import machine
from machine import Pin, PWM, mem32
from array import array
from rp2 import PIO, StateMachine, asm_pio
from uctypes import addressof
from ucollections import OrderedDict
from rp2040 import *
from rgb_led_controller import RgbLedController, color_sequence_extend

# https://docs.micropython.org/en/v1.10/reference/isr_rules.html
micropython.alloc_emergency_exception_buf(100)

PIO_BUF_SIZE = 1 << 16  # must be multiple of 4
assert (0 == (PIO_BUF_SIZE & 3))
pio_buf = bytearray(PIO_BUF_SIZE)
"""The singleton (but non-exclusive) sample buffer."""


class Pins:
    """Define the pins for the JS220 Evaluation Kit 1."""
    R_1 = 0
    R_10 = 1
    R_100 = 2
    R_1K = 3
    R_10K = 4
    R_100K = 5
    R_1M = 6
    R_10M = 7

    C_10U = 8
    C_PWM = 9
    EXT0 = 10
    EXT1 = 11
    EXT2 = 12

    GPIO13 = 13  # test point
    GPIO14 = 14  # test point
    GPIO15 = 15  # test point

    LED_BLUE = 16
    LED_RED = 17
    LED_GREEN = 18

    LDO_EN = 19
    BUCK_EN = 20

    VSET_BUCK_1V0 = 21
    VSET_BUCK_1V8 = 22
    VSET_BUCK_3V3 = 23

    UART_TX = 24
    UART_RX = 25

    VSET_LDO_1V8 = 26
    VSET_LDO_3V3 = 27
    GPIO28 = 28  # test point
    GPIO29 = 29  # not connected


_R_TO_MASK = {
    1: (1 << Pins.R_1),
    10: (1 << Pins.R_10),
    100: (1 << Pins.R_100),
    1_000: (1 << Pins.R_1K),
    10_000: (1 << Pins.R_10K),
    100_000: (1 << Pins.R_100K),
    1_000_000: (1 << Pins.R_1M),
    10_000_000: (1 << Pins.R_10M),
}


def r_to_mask(r):
    """Convert a desired resistance to the GPIO bitmap mask.

    :param r: The resistance in Ohms, which must exactly match
        on of the resistor values.
    :return: The integer bitmap mask.
    """
    return _R_TO_MASK[int(r)]


DEMO_SEQUENCES_BY_RESISTANCE = {
    # lists of [duration_clocks, resistance] entries
    'descend': [
        [1000, 1],
        [1000, 10],
        [1000, 1],
        [1000, 100],
        [1000, 10],
        [1000, 100],
        [1000, 10],
        [1000, 1_000],
        [1000, 100],
        [1000, 1_000],
        [1000, 100],
        [1000, 10_000],
        [1000, 1_000],
        [1000, 10_000],
        [1000, 1_000],
        [1000, 100_000],
        [1000, 10_000],
        [1000, 100_000],
        [1000, 10_000],
        [1000, 1_000_000],
        [1000, 100_000],
        [1000, 1_000_000],
        [1000, 100_000],
        [1000, 10_000_000],
        [1000, 1_000_000],
        [1000, 10_000_000],
        [1000, 1_000_000],
        [1000, 10_000_000],
    ],
}

DEMO_SEQUENCES_BY_MASK = {
    # lists of [duration_clocks, IO_mask] entries
    'wiggle': [
        [1000, 0x02],
        [100, 0x06],
        [1000, 0x02],
        [100, 0x06],
        [1000, 0x02],
        [100, 0x06],
        [1000, 0x02],
        [200, 0x06],
        [20, 0x0E],
        [200, 0x06],
        [20, 0x0E],
        [200, 0x06],
        [20, 0x0E],
        [200, 0x06],
        [20, 0x0E],
        [200, 0x06],
        [20, 0x0E],
        [200, 0x06],
        [5000, 0x40],
        [1000, 0x04],
        [100, 0x0C],
        [1000, 0x04],
        [100, 0x0C],
        [1000, 0x04],
        [100, 0x0C],
        [1000, 0x04],
        [200, 0x0C],
        [20, 0x1C],
        [200, 0x0C],
        [20, 0x1C],
        [200, 0x0C],
        [20, 0x1C],
        [200, 0x0C],
        [20, 0x1C],
        [200, 0x0C],
        [20, 0x1C],
        [200, 0x0C],
        [5000, 0x08],
        [5000, 0x10],
        [5000, 0x20],
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
    ],
}


def _u8_saturate(v):
    return min(255, max(0, int(v)))


def _u8_to_pwm(v):
    v = _u8_saturate(v)
    v += 1
    return 0xffff - ((v * v) - 1)


@asm_pio(out_init=(PIO.OUT_LOW, PIO.OUT_LOW, PIO.OUT_LOW, PIO.OUT_LOW,
                   PIO.OUT_LOW, PIO.OUT_LOW, PIO.OUT_LOW, PIO.OUT_LOW),
         out_shiftdir=PIO.SHIFT_RIGHT,
         autopull=True,
         pull_thresh=32,
         # fifo_join=PIO.JOIN_TX
         )
def _pio_program():
    out(pins, 8)  # set the output pins with the buffer data
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

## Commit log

2022-09-12 Initial commit.
    [js220_evk1.brd, js220_evk1.sch, js220_evk1_bom.xlsx]
2022-09-12 Fixed README schematic link.
2022-09-14 Added detail to "Current rating exceeded" error message.
    [evk.py]
2022-09-16 Added BOM
    [js220_evk1_top_b-bom.csv]
